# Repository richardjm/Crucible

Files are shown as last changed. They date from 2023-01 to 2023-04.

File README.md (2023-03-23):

# Crucible

## Features

* A VORON Trident on a V0 scale
* Overall dimensions (mm): 230x230x360
* Build volume (mm): 120x120x120
* Klicky Probe integration
* Quick release panels
* Under-bed carriage fans
* Fancy name

## Variant

* [Stealth skirts](https://github.com/VoronDesign/VoronUsers/tree/master/printer_mods/Maverick/V0.2_Stealth_Skirts) with modifications to rear parts
* [Display from 0.2](https://github.com/VoronDesign/Voron-0)

## Recoloured variant

The CAD contains three colours

* _PrimaryColour (e.g. Black) - majority of parts
* _AccentColour (e.g. Red) - a few highlights
* _TouchColour (e.g. Black) - parts that are touched (handle, panel tabs etc), you would tend to adjust this is you have a pale_PrimaryColour - see second image.

### "Standard" Voron

* Primary = Black
* Accent = Red
* Touch = Black

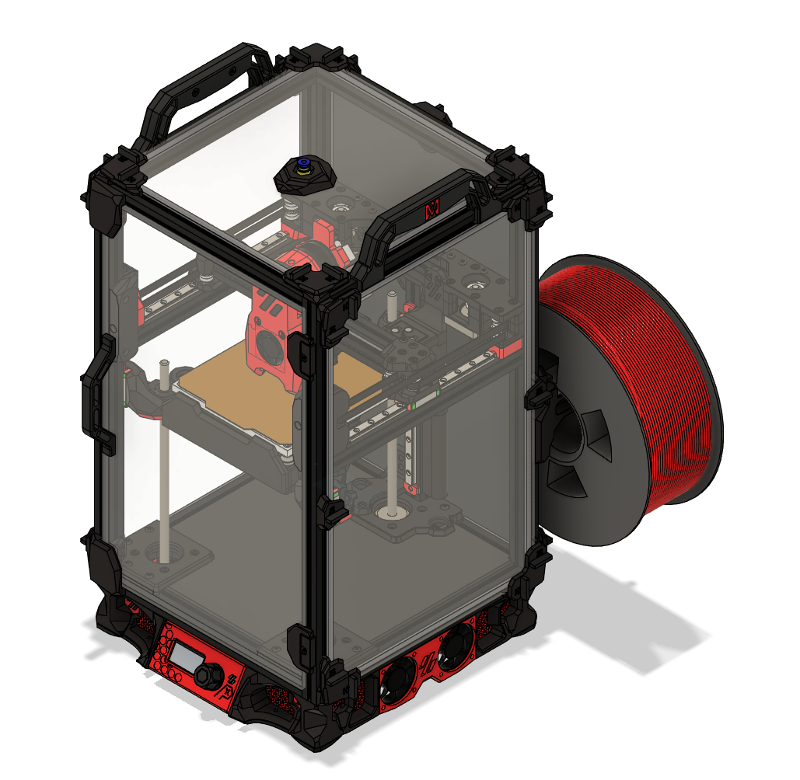
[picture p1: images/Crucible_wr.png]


### Black on White

* Primary = White
* Accent = Black
* Touch = Black

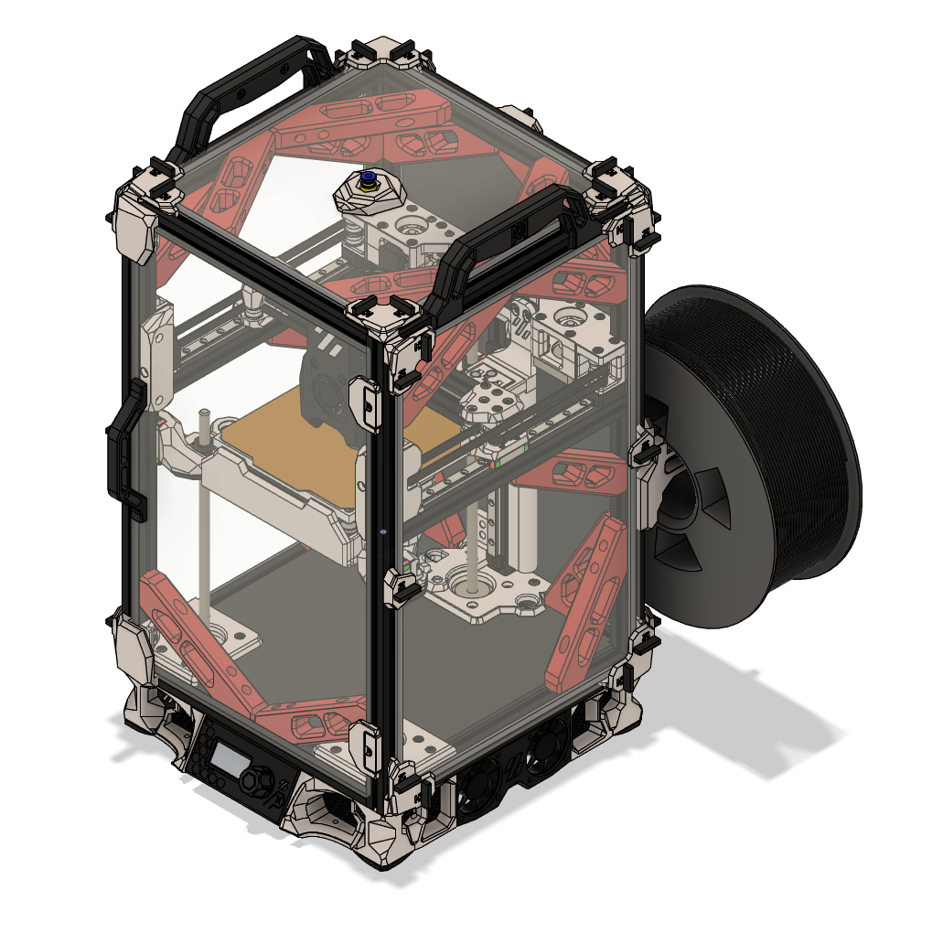
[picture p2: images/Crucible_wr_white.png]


## Original

Render




## Work in Progress

Please bear in mind that this is a WIP - please be patient as the existing design is improved upon and stay up to date at the [Discord channel](https://discord.gg/UQzPxNhA92).

## Parts Needed for V0.1 Conversion

* (4) 360mm 1515 Extrusions
* (3) IGUS GE5C Spherical Bearings
* (2) NEMA17 Stepper Motor w/ integrated lead screw 200mm T8x8
* (8) F623 Bearings
* (4) 4010 Fans - For Skirt and Bed
* (1) 150mm MGN9C Linear Rail
* MCU capable of handling additional steppers (dual or otherwise)
* 3mm foam strips
* Acrylic panels
* Misc. M3 hardware of varying lengths

## Recognition

* Nemgrea#4325 / VORON Design [V0.1](https://vorondesign.com/voron0.1)
* Slayga#8084
* Mike4D#8668
* hartk#1213 [Micron Parts](https://github.com/hartk1213/Micron)
* MCMBen#6371  [Trident Skirt](https://github.com/Fleafa/VoronUsers/tree/V0.1-Trident-skirt/printer_mods/MCMBen/Voron0_Trident_Skirt)

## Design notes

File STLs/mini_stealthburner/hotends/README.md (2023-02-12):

https://github.com/VoronDesign/Voron-0/tree/Voron0.2/STLs/Toolheads/Hotend_Mounts

FS (Fan Saver) - some gdstime blowers stop working at temperature mounts to insulate them a bit.

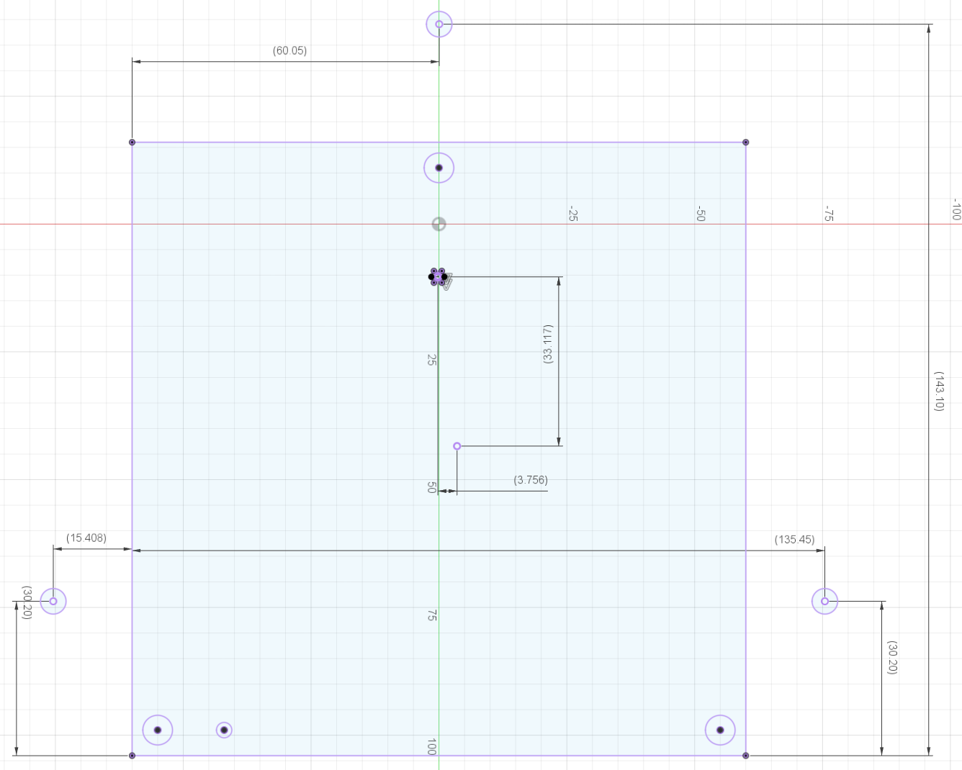
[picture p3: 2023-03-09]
CAD/z_tilt.png

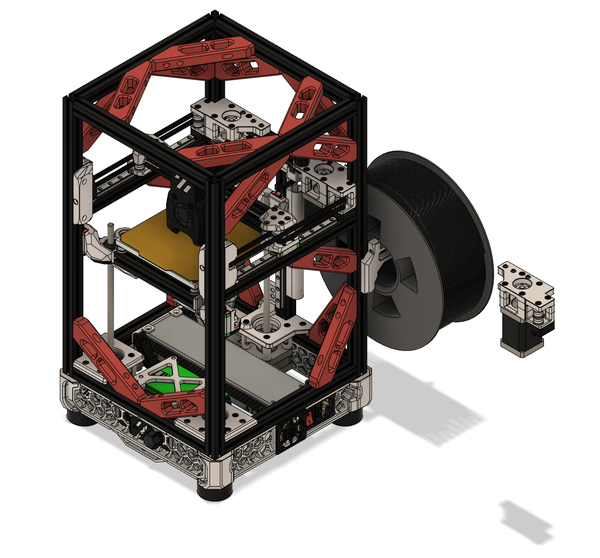
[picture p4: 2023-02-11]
Usermods/richardjm/everywhere-brace/18-braces.png

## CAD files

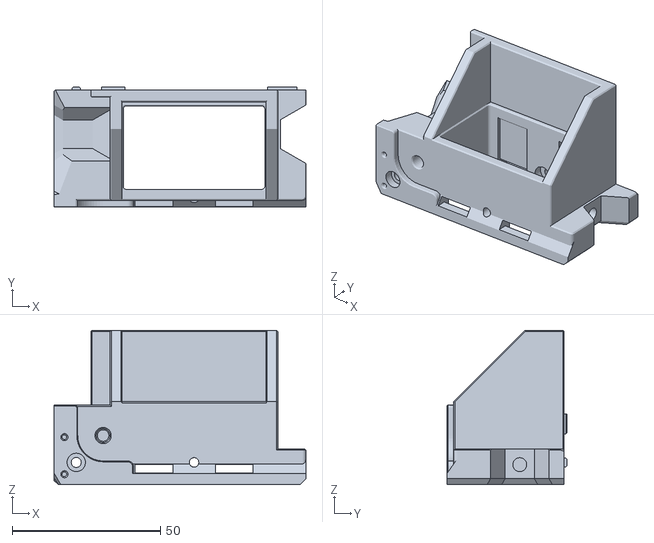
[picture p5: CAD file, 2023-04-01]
STLs/stealth_skirts/Mains_Inlet_Foot_Crucible_x1.stl
84.9 x 40.5 x 52.0

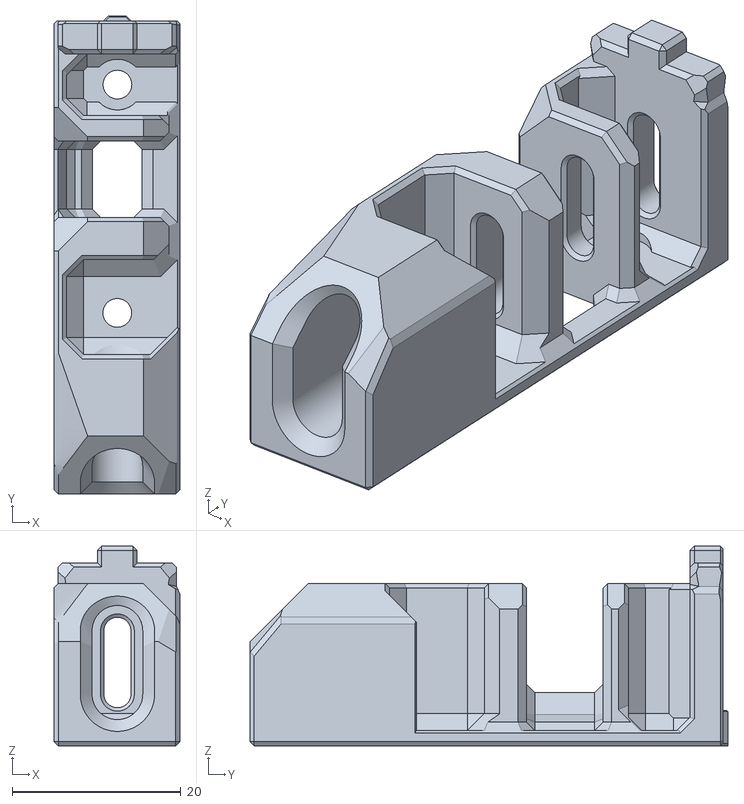
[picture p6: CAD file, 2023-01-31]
STLs/gantry/b_idler_main.stl
14.9 x 56.6 x 23.7

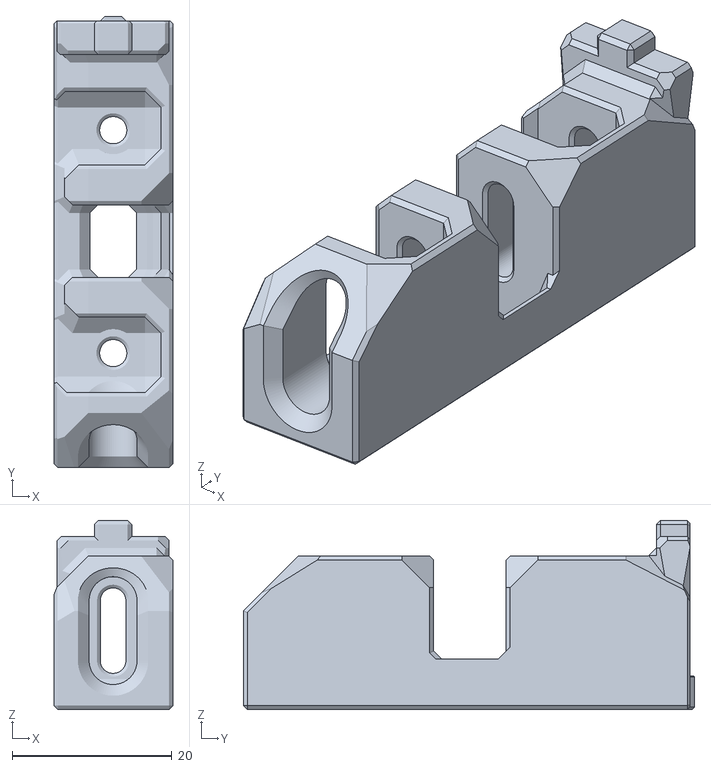
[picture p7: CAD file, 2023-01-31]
STLs/gantry/a_idler_main.stl
14.9 x 56.5 x 23.7

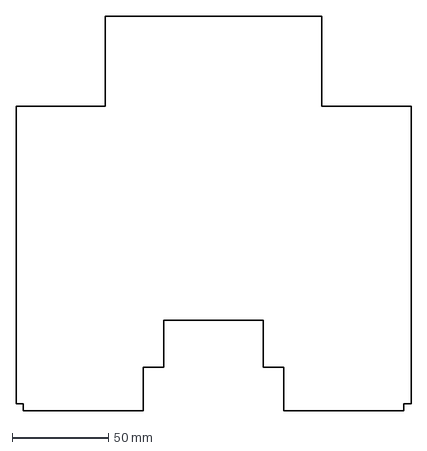
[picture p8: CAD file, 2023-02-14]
CAD/BasePanel.dxf
205.6 x 205.3 mm

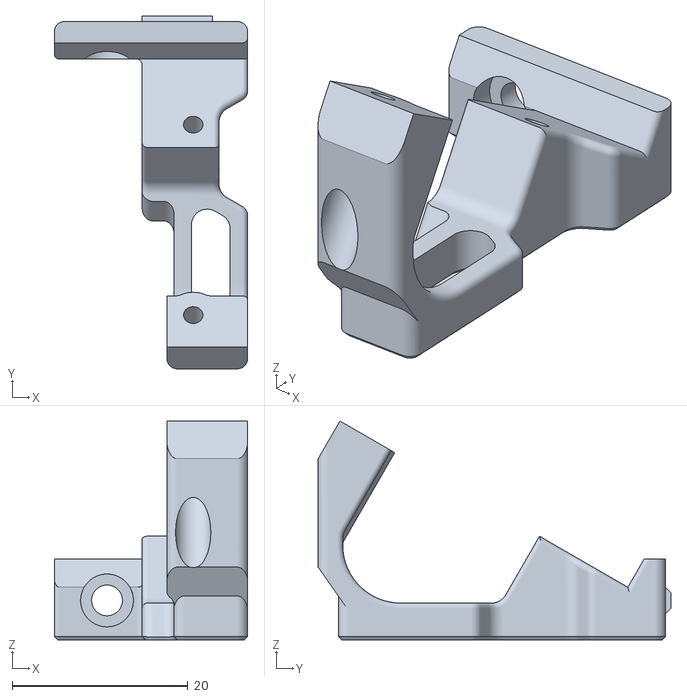
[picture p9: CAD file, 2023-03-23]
STLs/display/Display_Mount_Right_x1.stl
22.0 x 40.1 x 24.9

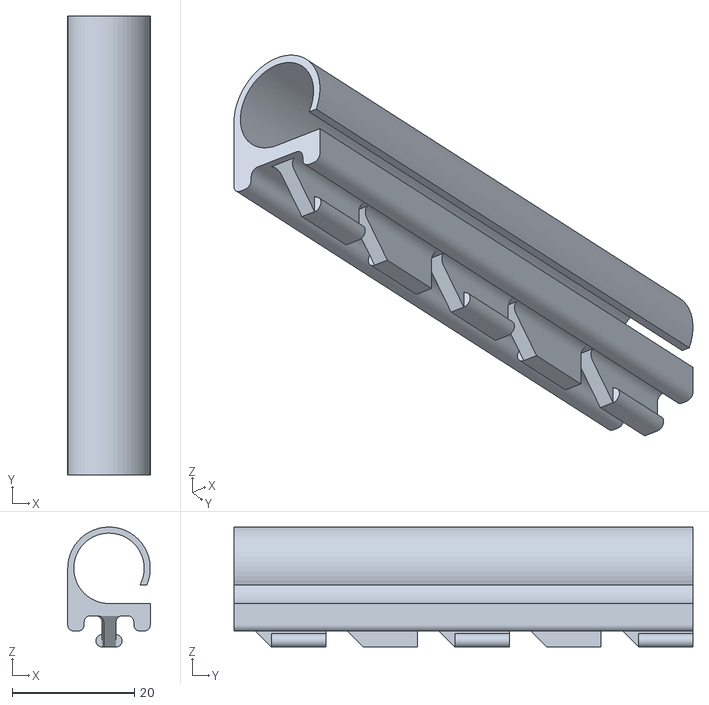
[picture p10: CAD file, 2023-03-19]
STLs/frame/sawtooth_cable_75x2.stl
13.5 x 75.0 x 19.6

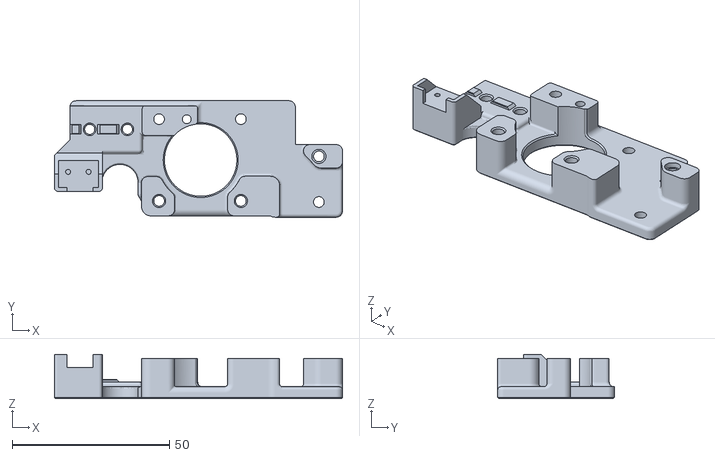
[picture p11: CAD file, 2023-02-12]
STLs/gantry/a_drive_lower.stl
91.5 x 37.0 x 14.0

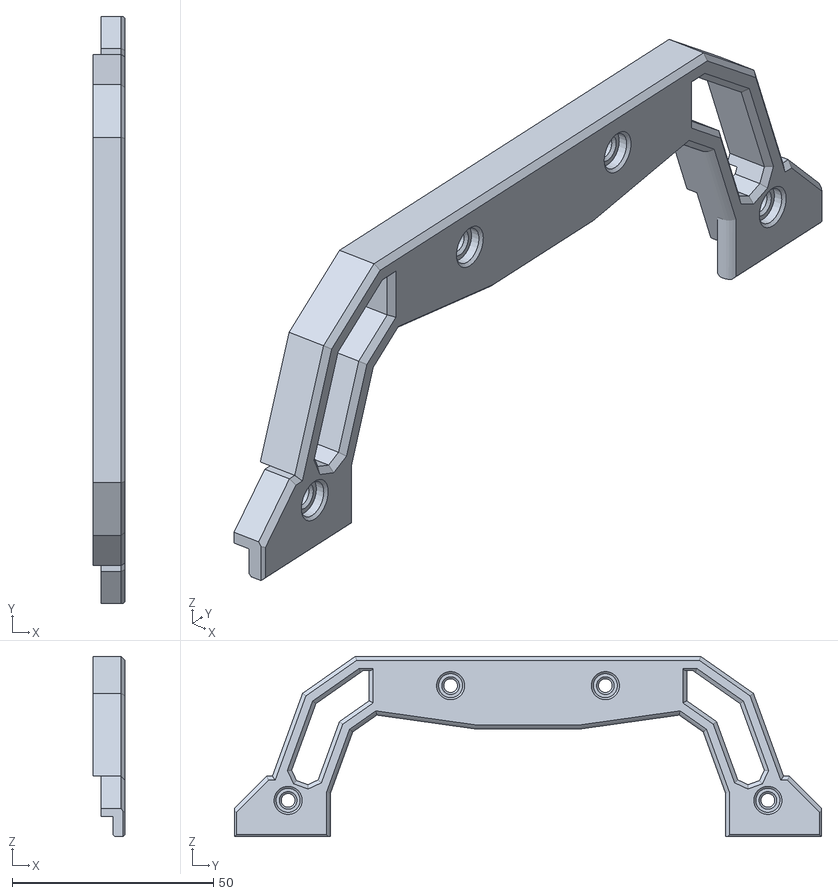
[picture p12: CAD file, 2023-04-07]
STLs/handles/[t]_handle_x2.stl.stl
8.00 x 145.7 x 44.8

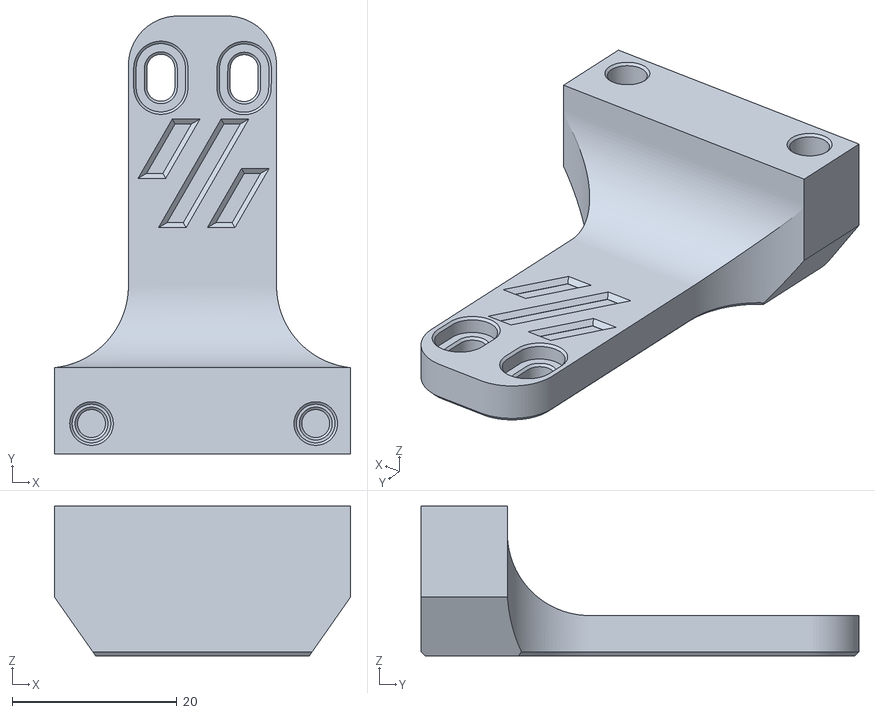
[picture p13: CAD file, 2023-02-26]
STLs/klicky/dock_mount_fixed.stl
36.0 x 53.2 x 18.2

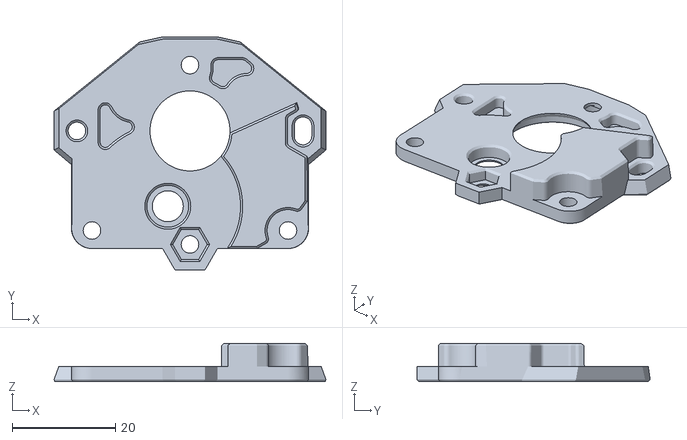
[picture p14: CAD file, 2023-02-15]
STLs/mini_stealthburner/[a]_motor_plate.stl
52.7 x 45.2 x 7.40

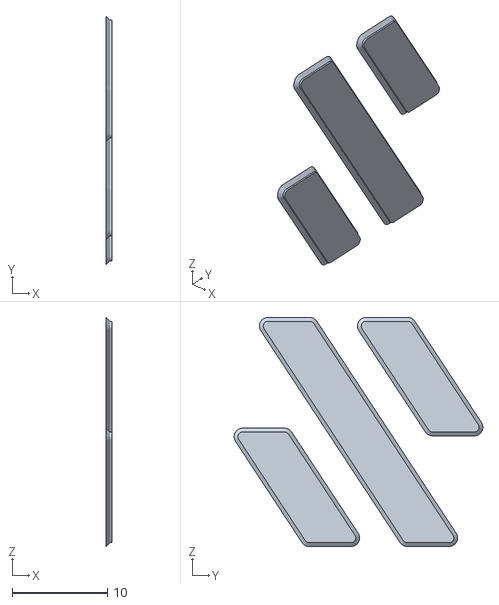
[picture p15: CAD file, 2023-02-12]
STLs/mini_stealthburner/embossed_cowling/front_cowling_logo_insert.stl
0.6 x 26.1 x 24.0

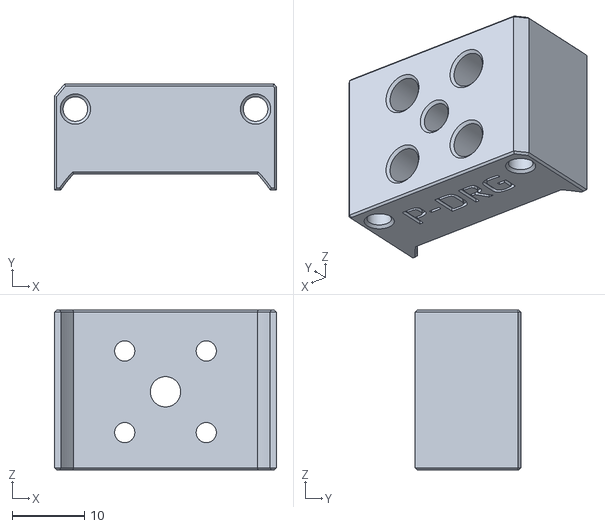
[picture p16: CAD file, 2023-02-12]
STLs/mini_stealthburner/hotends/[a]_Hotend_Mount_Dragon.stl
30.8 x 14.7 x 22.2

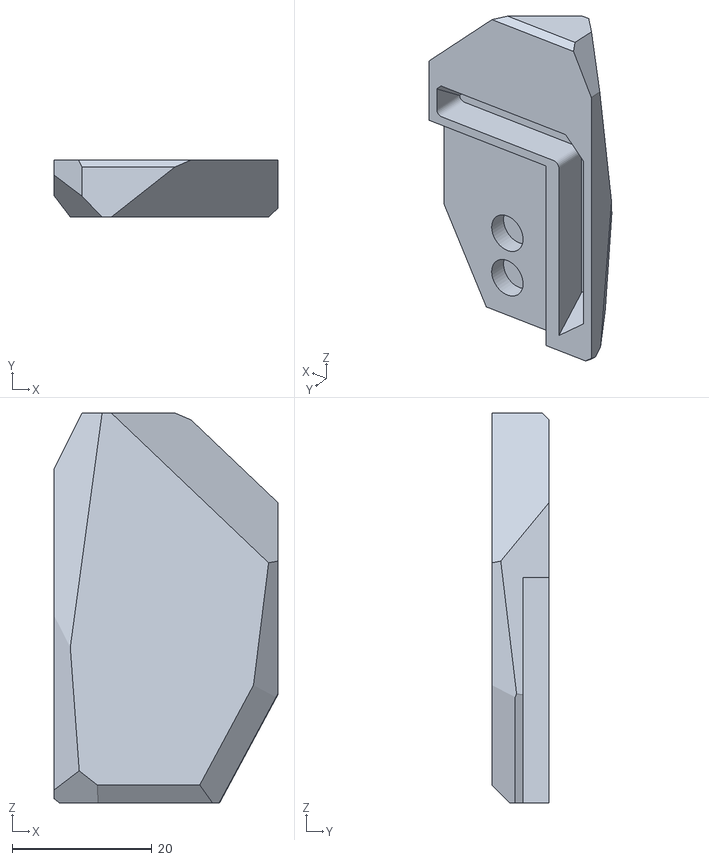
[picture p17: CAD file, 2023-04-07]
STLs/panels/[t]_handle_front_corner.stl
32.0 x 8.16 x 55.8

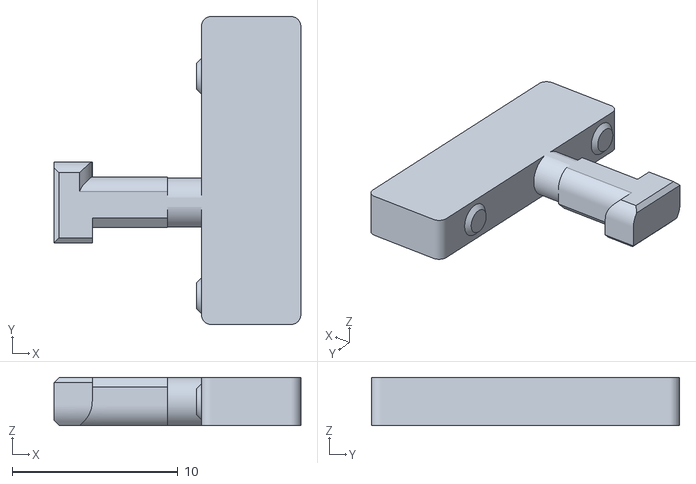
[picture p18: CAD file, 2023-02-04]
STLs/panels/clip_2.8/[t]_panel_key_2.8.stl
14.9 x 18.6 x 2.90

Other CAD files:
STLs/panels/clip_3.8/panel_clip_corner_3.8.stl
STLs/panels/clip_4.8/[t]_panel_key_4.8.stl
STLs/panels/clip_7.0/panel_clip_center_7.0.stl
STLs/spool_holder/[a]_filament_guide_6mm.stl
CAD/1515DrillGuide v4.f3d
CAD/Crucible_Clips_Smaller.f3d
CAD/Y_Extrusion_Positioner v4.f3d
STLs/display/Display_Knob_x1.stl
STLs/display/Display_Mount_Left_x1.stl
STLs/display/[a]_Display_Faceplate_x1.stl
STLs/display/[c]_Display_Diffuser.STL
STLs/frame/[a]_rail_stop_x6.stl
STLs/frame/[t]_handle_a_x2.stl
STLs/frame/[t]_handle_b_x2.stl
STLs/frame/rear_vertical_brace.stl
STLs/frame/rear_vertical_brace_m3x20.stl
STLs/gantry/[a]_a_drive_corner.stl
STLs/gantry/[a]_a_idler_pulley.stl
STLs/gantry/[a]_b_drive_corner.stl
STLs/gantry/[a]_b_idler_pulley.stl
STLs/gantry/a_drive_lower_no_fittings.stl
STLs/gantry/a_drive_upper.stl
STLs/gantry/a_drive_upper_no_fittings.stl
STLs/gantry/a_idler_adjuster.stl
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

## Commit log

2023-01-31 Fist STL export - wip
    [A_Drive_Corner.stl, A_Drive_Lower[A].stl, A_Drive_Upper[A].stl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]
2023-01-31 Add no logo variant
    [A_Idler_Adjuster_NoLogo.stl, B_Idler_Adjuster_NoLogo.stl]
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2023-01-31 Print orientation
    [A_Idler_Adjuster_NoLogo.stl, B_Idler_Adjuster_NoLogo.stl]
2023-01-31 Change to voron naming
    [[a]_a_drive_lower.stl, [a]_a_drive_upper.stl, [a]_a_idler_main.stl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]
2023-01-31 Rename folder
    [[a]_a_drive_lower.stl, [a]_a_drive_upper.stl, [a]_a_idler_main.stl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]
2023-01-31 More stls
    [[a]_door_hinge_plate_x2.stl, [a]_door_hinge_x2.stl, [a]_door_latch_bottom.stl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]
2023-01-31 Will it never end
    [[a]_panel_clip_center_x4.stl, [a]_panel_clip_corner_x12.stl, panel_clip_center_x2.stl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]
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2023-02-03 Reflect colouring in filenames
    [[a]_a_drive_corner.stl, [a]_b_drive_corner.stl, [a]_rail_stop_x6.stl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]
2023-02-03 Mostly re-orientations
    [[a]_skirt_fan_cover_x2.stl, [a]_skirt_front_center_logo_inset.stl, [a]_skirt_logo_x2.stl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]
2023-02-04 Panel clips in CAD seem too thick
    [[t]_panel_key_2.8.stl, [t]_panel_key_7.0.stl, panel_clip_center_2.8.stl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]
2023-02-06 Lowers are alt - still not sure about the rear one though
    [[a]_z_left_lower.stl, [a]_z_rear_lower.stl, [a]_z_rear_lower_circular.stl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]
2023-02-06 Attempt to make feet printable, more consistent
    [foot_front_right.stl, foot_inlet.stl, foot_left_x2.stl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]
2023-02-11 I seem to have the wrong nut type - but not sure this fits in any way
    [z_rear_lower_circular_tnut.stl]
2023-02-11 Extra m3 for the rear extrusion
    [rear_vertical_brace_m3x20.stl]
2023-02-11 Modification for no endstop or umbilical mount
    [a_drive_lower_no_fittings.stl, a_drive_upper_no_fittings.stl]
2023-02-11 Should make these parameterisable
    [crucible_led_sawtooth_100mm.stl, crucible_led_sawtooth_199mm.stl]
2023-02-11 Braces for you, and you, and you!
    [CrucibleBrace.stl]
2023-02-12 ab screw in holes too large
    [a_drive_lower.stl, a_drive_lower_no_fittings.stl, b_drive_lower.stl]
2023-02-12 Starting mini-sb export prior to printing
    [Strain_Relief_Test_1.stl, Strain_Relief_Test_2.stl, Strain_Relief_Test_3.stl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]
2023-02-12 Some drill guides - seem to work well on a pillar drill
    [1515DrillGuide.stl, 1515DrillGuide2.stl]
2023-02-13 Rail stop
    [[a]_rail_stop_x6.stl]
2023-02-13 More tools
    [1515DrillGuide2.stl, y_extusion_positioner.stl]
2023-02-13 Orient for printing
    [CrucibleBrace.stl]
2023-02-13 Organise cowling etc
    [[a]_front_cowling.stl, [t]_shuttle.stl, front_cowling_logo_insert.stl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]
2023-02-14 Plate braces, plate cuts redone, more cad
    [1515DrillGuide v4.f3d, CrucibleBrace v5.f3d, CrucibleBrace.stl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]
2023-02-14 Add my version of the base plate dxf
    [BasePanel.dxf]
2023-02-15 Missed motor plate
    [[a]_motor_plate.stl]
2023-02-16 Fly mount
    [FlySht36v2Mount.stl]
2023-02-16 can board sat way too far away from my 17mm pancake motor - closed the gap by 4mm
    [[a]_strain_relief_spacer_x2.stl, [a]_x_carriage.stl]
2023-02-17 Even slimmer x
    nyloc captive nuts and m3x40
    [[a]_strain_relief_spacer-4_x2.stl, [a]_strain_relief_spacer_extra_beef-4_x2.stl, [a]_strain_relief_spacer_extra_beef-5.95_x2.stl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]
2023-02-17 Nyloc spun, slightly less beef
    [[a]_strain_relief_spacer_extra_beef-4_x2.stl, [a]_strain_relief_spacer_extra_beef-5.95_x2.stl, [a]_x_carriage-5.95.stl]
2023-02-24 Vague idea for more space in the electronics bay
    [z_stepper_rear.stl]
2023-02-24 Extra space if needed from rail stops
    [rail-stop.stl]
2023-03-04 Cover for front facing electrics
    [FrontBedCover.stl]
2023-03-04 Idler snapped - extra beef variant - needs supports
    [idler_b_arm.stl, idler_b_housing.stl, idler_b_plate.stl]
2023-03-04 Missing top bolt indent
    [idler_b_arm.stl]
2023-03-05 More clip size variation
    [Crucible_Clips_Smaller v3.f3d, Crucible_Clips_Smaller.f3d, [t]_panel_key_2.8.stl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]
2023-03-06 UnklickNG BFP WR
    [CrucibleUnKlickyNG v3.f3d, KlickyNG_BFP_Unklicky_Pin_3mm.stl, KlickyNG_BFP_Unklicky_WhistlinRic_Back.stl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]
2023-03-06 sawtooth cable run
    [sawtooth_cable_74_x2.stl]
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2023-03-13 Chunky wedge
    [ProbeMount_Body3_Wedge.stl]
2023-03-17 Cable runs CAD
    [Z_ChainMount_w_cable.stl, z_stepper_rear_w_cable.stl]
2023-03-17 Taller front cover for 15mm brass spacers
    [FrontBedCover-15mmBrassSpacer.stl]
2023-03-18 Fix hole and chamfers
    [Z_ChainMount_w_cable.stl]
2023-03-18 Add zip tie slot - untested
    [Z_ChainMount_w_cable.stl]
2023-03-19 puppet mounts and other things
    [Puppet.stl, PuppetPi.stl, Spacer1_x2.stl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]
2023-03-23 New skirts, images, stls, the lot
    [3510_Fan_Grill_x2.stl, 3510_Side_Skirt_Mid_x2.stl, 4010_Fan_Grill_x2.stl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]
2023-04-01 A few more updates - partially tested
    [4010_Side_Skirt_Mid_Solid_x2.stl, Display_Blankingplate.stl, Mains_Inlet_Foot_Crucible_x1.stl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]
2023-04-02 Supported style
    [door_hinge_m3x40_x2.stl]
2023-04-07 Spool stuff
    [[a]_filament_guide.stl, [a]_spool_holder.stl]
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2023-04-13 Other idler idea on printer
    [IdleIdea2 v11 - RailStop.stl, IdleIdea2 v8 - Block.stl, IdleIdea2 v8 - BlockA.stl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]
2023-04-13 Added .95 of beef to the wings
    [IdleIdea2 v13 - BlockA.stl, IdleIdea2 v13 - BlockB.stl, IdleIdea2 v13 - CarrierA.stl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]
2023-11-12 Sliced front to allow space for the front brace
    [[a]z_left_lower_sliced.stl, [a]z_right_lower_sliced.stl, z_left_upper_sliced.stl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]
2025-10-05 Quick export of the extrusionless-x for Crucible
    [Boop_Upper_PCB v8.stl, XY_Joint_Left_Lower.stl, XY_Joint_Left_RailSupport.stl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]
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
